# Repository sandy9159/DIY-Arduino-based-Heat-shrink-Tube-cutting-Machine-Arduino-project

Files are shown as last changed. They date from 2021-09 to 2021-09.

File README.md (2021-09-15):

# DIY-Arduino-based-Heat-shrink-Tube-cutting-Machine-Arduino-project

GK

Hey guys this time I have made a heat shrink tube cutting machine, heat shrinks are frequently needed in small length, 

manually cutting them is to boring job so I build this mini machine it can cut heat shrink from 2mm to 8mm in any length and quantity, 

user just have to insert data from HMI and need to press start so this machine automatically start cutting heat shrink tube.

In this machine first user will feed the heat shrinkk tube in between two slider rollers.

Then user have to provide some data using HMI like length of Heat shrink and quantity of heat shrink tube.

## COMPONENT USED

1. Custom PCB 
2. Arduino Nano
3. A4988 Stepper driver
4. High torque stepper motor
5. Nema 17 stepper motor 
6. some ball joint rod
7. 8mm smooth rod
8. SC8UU linear bearing
9. Nextion HMI

# CIRCUID DRAWING 

Making such projects without PCB is night mare yes trust me
you cannot get wanted result and professional touch in your project if you ignore PCB
So some days back I have developed my Multipurpose PCB.
This PCB is used to build wide range of arduino projects 

Schematic_Multipurpose pcb_2021-09-15

followings are the some features of PCB

1. Wide range of power input 9V to 24V DC
2. Cross polarity protection
3. DC motor voltage selection 9V or 12 V DC
4. Servo motor voltage selection 5V or 9V DC
5. Manual microstepping setting for stepper motor
6. Power indication LED
7. L298N IC for heavier DC motor
8. ON board 5V and 9V regulator no need to arrange different power sources
9. Header pins and screw terminals for easy connections

List of the Components you can connect to the PCB

1. 2 DC motor ( 9V to 24V DC)
2. 2 Potentiometer
3. 2 Servo motors ( 5V to 9V DC)
4. 1 Serial device (BT module, HMI, Communication module, RX, TX)
5. 1 Encoder (2 interrupt pin & 1 PB pin)
6. 1 I2C device (SCL/SDA Device, display, MPU6050 etc)
7. 2 Stepper motors 

MVI_0001 00_06_45_21 Still003
MVI_0001 00_07_21_22 Still004

I have design circuit and PCB in [easyEDA](https://easyeda.com/) and ordered PCB from [JLCPCB](https://jlcpcb.com/IAT )

This is the link of [PCB editabl file](https://oshwlab.com/sharmaz747/multipurpose-pcb)

If you seriously need quality PCB quickly in your hand then you must have to try [JLCPCB](https://jlcpcb.com/IAT ) PCB manufacturing service.
They have Special offer of $2 for 1-4 Layer PCBs, free SMT assembly monthly.
If you get yourself registered today at [JLCPCB](https://jlcpcb.com/IAT ) you get 18$ welcome coupon from [JLCPCB](https://jlcpcb.com/IAT ).



The base of this machine is made from 12mm thick wooden base I have cut it in size of 230 x 210 mm

I have placed the rubber leg at the bottom of the base for better grip



Then I installed some vertical sliding arrangment like I hold 8mm SS smooth rod with the help of 8mm shaft holder

and I have SC8UU 8MM Linear bear 



I have printed some parts in my 3D printer using PLA filament with 50 % infill

This parts are used for holding Servo motor, holding cutter blade and for holding Stepper motors

you can get all the 3D files from the link 

https://pinshape.com/items/107790-3d-printed-diy-arduino-based-heat-shrink-tube-cutting-machine

Capture

This is the HMI screen of the machine user can input data like LENGTH means how long tube need to cut and QTY means how many tubes needs to be cut 

and the as soon we press START the machine starts running...

MVI_0001_3_1

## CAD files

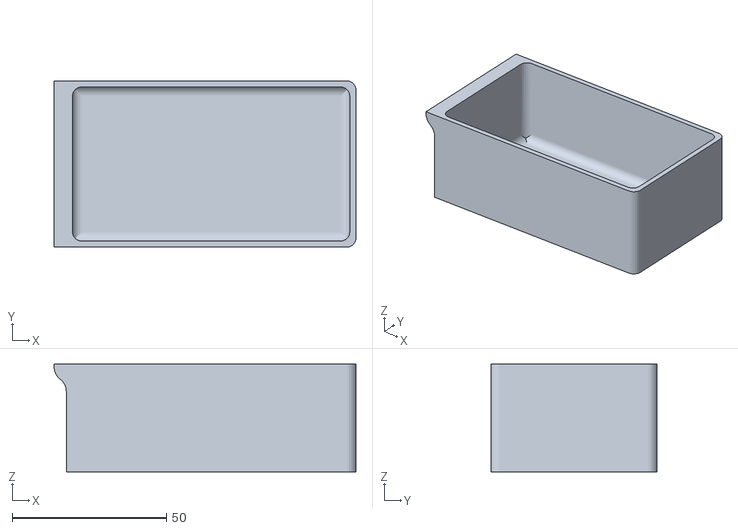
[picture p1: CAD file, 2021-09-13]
STL/container.stl
98.0 x 54.0 x 35.0

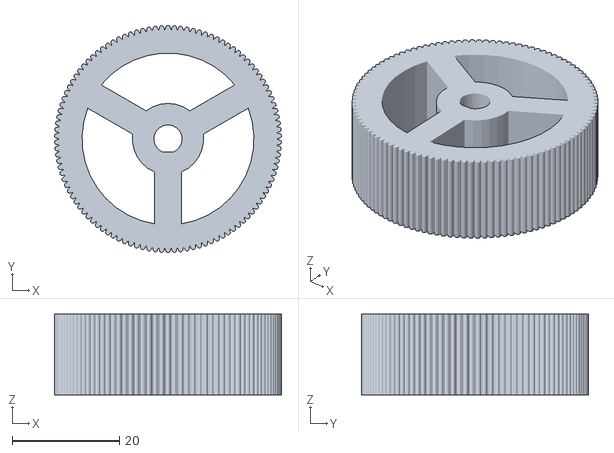
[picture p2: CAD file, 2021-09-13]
STL/roller down.stl
42.3 x 42.3 x 15.0

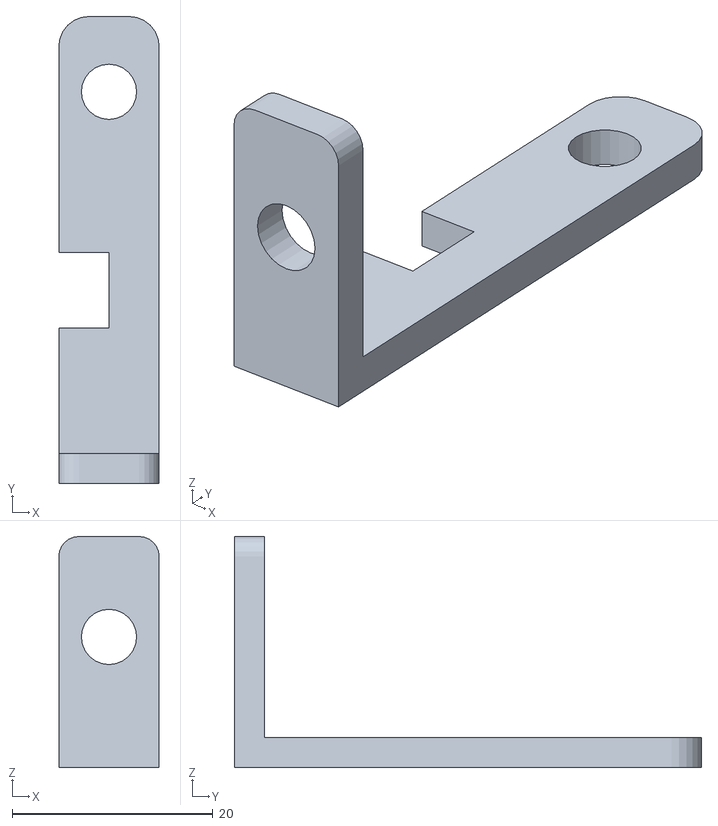
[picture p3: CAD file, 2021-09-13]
STL/tube guider.stl
10.00 x 46.5 x 23.0

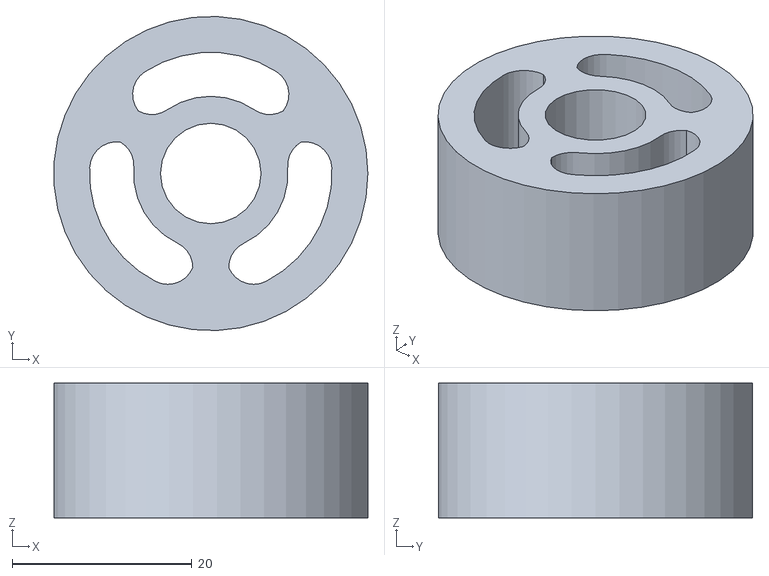
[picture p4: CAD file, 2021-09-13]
STL/roller up.stl
34.9 x 35.0 x 15.0

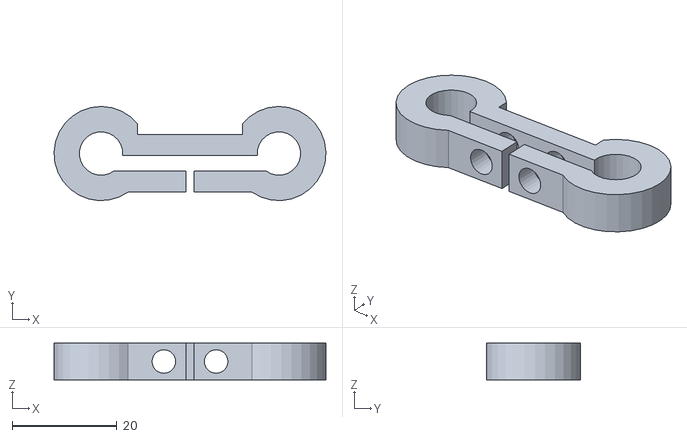
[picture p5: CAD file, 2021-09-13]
STL/servo holder.stl
52.0 x 18.0 x 7.00

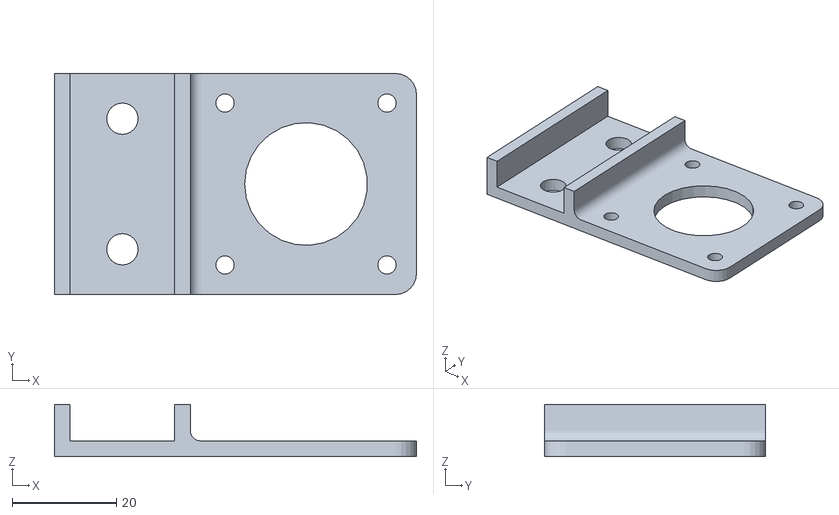
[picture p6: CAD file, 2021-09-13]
STL/stepper motor holder.stl
69.3 x 42.3 x 10.00

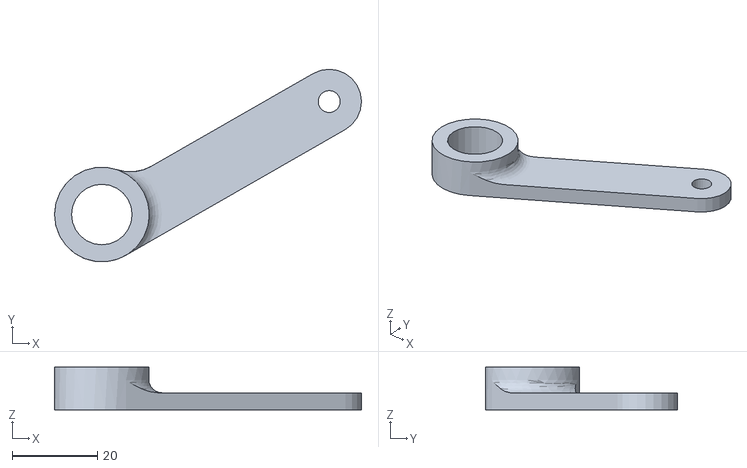
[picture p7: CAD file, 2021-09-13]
STL/tension arm.stl
72.0 x 45.1 x 10.00

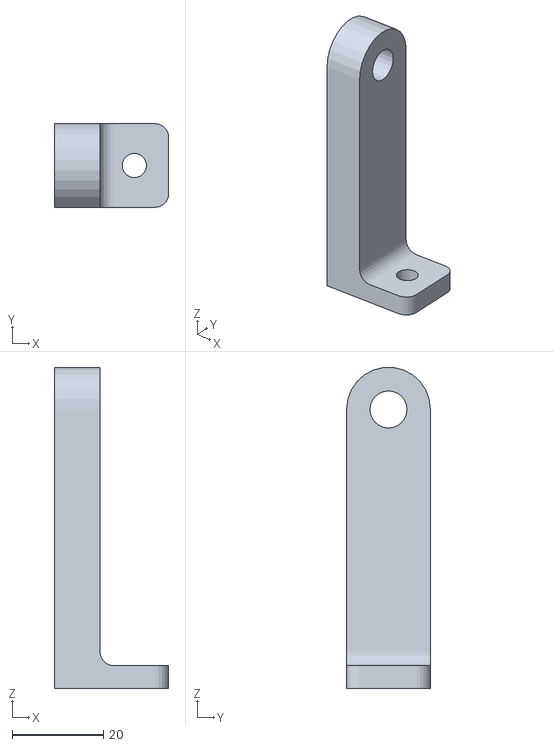
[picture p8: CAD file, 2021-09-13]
STL/metal tube holder.stl
25.0 x 18.3 x 70.2

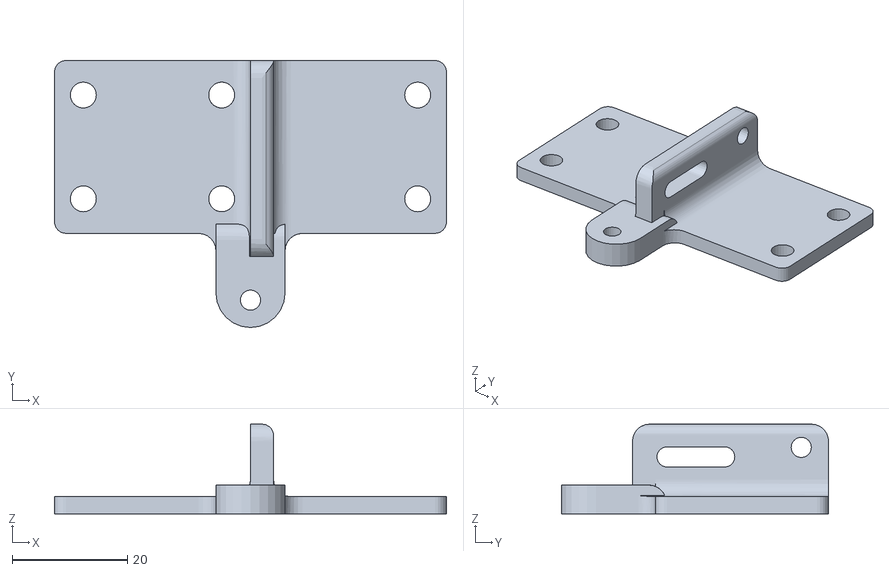
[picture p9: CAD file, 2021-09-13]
STL/blade holder.stl
68.0 x 46.3 x 15.6

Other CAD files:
STL/files.stl

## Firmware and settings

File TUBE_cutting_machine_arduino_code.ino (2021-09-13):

#include <Stepper.h>
#include <Arduino.h>
#include "BasicStepperDriver.h"
#include <SoftwareSerial.h>
#include <Servo.h>

SoftwareSerial mySerial(2, 3); // RX, TX
Servo myservo;  

int A = 0;
int B = 0;
int state = 0;
String message;
int QTY, numMessages, endBytes;
byte inByte;
int flag = 0;



#define MOTOR_STEPS 200
#define RPM 40
#define MICROSTEPS 16
#define DIR 14
#define STEP 15
int pos = 0;


BasicStepperDriver stepper(MOTOR_STEPS, DIR, STEP);



void setup()
{
  numMessages, endBytes = 0;
  
  
  Serial.begin(9600);
  mySerial.begin(9600);
  myservo.attach(5); 
  myservo.write(180);
  stepper.begin(RPM, MICROSTEPS);
  delay(1000);
  
}

void loop()
{
  data();
  
  if (A > 0 && B > 0) {
    delay(1000);
    
myservo.write(70);
delay(1000);
    for (int i = 0; i < B; i++) {

 stepper.rotate(-(2.75*A));
 cut();

    }
    A=0;
    B=0;

  }
}

  void data() {
    if (state < 1) {
      if (numMessages == 1) { //Did we receive the anticipated number of messages? In this case we only want to receive 1 message.
        A = QTY;
       // Serial.println(A);//See what the important message is that the Arduino receives from the Nextion
        numMessages = 0; //Now that the entire set of data is received, reset the number of messages received
        state = 1;
      }
    }

    if (state > 0) {
      if (numMessages == 1) { //Did we receive the anticipated number of messages? In this case we only want to receive 1 message.
        B = QTY;
       // Serial.println(B);//See what the important message is that the Arduino receives from the Nextion
        numMessages = 0; //Now that the entire set of data is received, reset the number of messages received
        state = 0;
      }
    }






    if (mySerial.available()) { //Is data coming through the serial from the Nextion?
      inByte = mySerial.read();

      // Serial.println(inByte); //See the data as it comes in

      if (inByte > 47 && inByte < 58) { //Is it data that we want to use?
        message.concat(char(inByte)); //Cast the decimal number to a character and add it to the message
      }
      else if (inByte == 255) { //Is it an end byte?
        endBytes = endBytes + 1; //If so, count it as an end byte.
      }

      if (inByte == 255 && endBytes == 3) { //Is it the 3rd (aka last) end byte?
        QTY = message.toInt(); //Because we have now received the whole message, we can save it in a variable.
        message = ""; //We received the whole message, so now we can clear the variable to avoid getting mixed messages.
        endBytes = 0; //We received the whole message, we need to clear the variable so that we can identify the next message's end
        numMessages  = numMessages + 1; //We received the whole message, therefore we increment the number of messages received.

        //Now lets test if it worked by playing around with the variable.

      }
    }
  }

  void cut (){
    for (pos = 70; pos <= 180; pos += 1) { 
    myservo.write(pos);              
    delay(5);        
  }

  for (pos = 180; pos >= 70; pos -= 1) { 
    // in steps of 1 degree
    myservo.write(pos);              
    delay(10);                       
  }
  }
  
